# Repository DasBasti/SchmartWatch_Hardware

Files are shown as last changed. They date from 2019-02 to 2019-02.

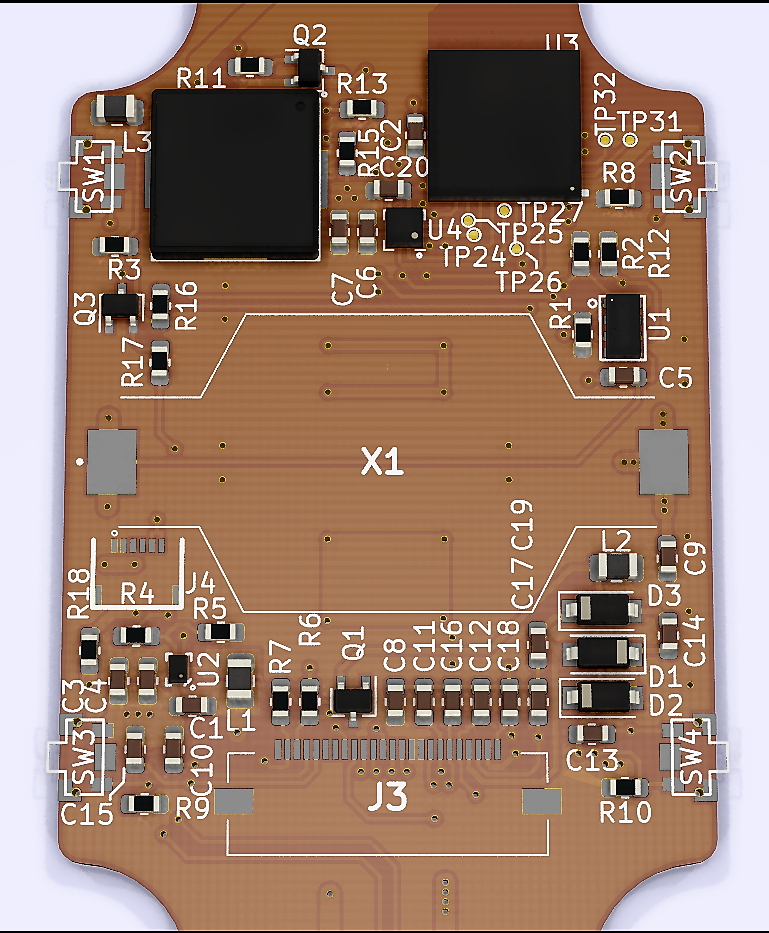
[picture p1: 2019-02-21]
render.png

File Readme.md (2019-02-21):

# Schmart Watch Hardware
Image of PCB rendering
## Table of Contents

- [Introduction](#introduction)
- [Terms of Use](#terms-of-use)
- [Problems?](#problems)
- [Changelog](#changelog)

## Introduction

This application is the hardware for the DIY Smartwatch project [Schmart Watch](http://www.kurzschluss-blog.de/2018/07/schmartwatch-01-smartwatch-selbst-gebaut.html).

To open the project you need [KiCad Version 5.0.0-rc2](http://kicad-pcb.org/) or newer.

## Terms of Use

Refer to "License.txt" for terms of use.

## Problems?

If you have any problems or questions, please ensure you have read this readme
file. If you are still having trouble, you can
[get in contact](https://plus.google.com/+BastianNeumann_DasBasti).

## Changelog

1. 2019-02-20: Version 0.1
  - Initial release of hardware version E3 for review

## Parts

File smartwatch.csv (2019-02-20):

Source: | C:\Users\Bastian\Documents\SmartWatch\Hardware\E3\smartwatch\smartwatch.sch
Date: | 24/09/2018 22:39:27
Tool: | Eeschema (5.0.0-rc2-109-g0e3be5776)
Generator: | C:\Program Files\KiCad\bin\scripting\plugins/bom_csv_grouped_by_value.py
Component Count: | 61
Individual Components:
Item | Qty | Reference(s) | Value | LibPart | Footprint | Datasheet | MPN1 | MPN2 | Package | Price | Status | Supplyer and ref
 |  | C1 | 10u/4V | Device:C | Capacitor_SMD:C_0603_1608Metric | https://www.mouser.de/datasheet/2/212/KEM_C1006_X5R_SMD-1103249.pdf | CL10A106MQ8NNNC | GRM188R60J106ME84D | 603 | 0,02363
 |  | C2 | 100n/6.3V | Device:C | Capacitor_SMD:C_0603_1608Metric | https://www.mouser.de/datasheet/2/281/murata_03052018_GRM_Series_1-1310166.pdf | GCM188R71C104KA37D | 0603YC104MAT2A | 603 | 0,01188
 |  | C3 | 10u/4V | Device:C | Capacitor_SMD:C_0603_1608Metric | https://www.mouser.de/datasheet/2/212/KEM_C1006_X5R_SMD-1103249.pdf | CL10A106MQ8NNNC | GRM188R60J106ME84D | 603 | 0,02363
 |  | C4 | 10u/4V | Device:C | Capacitor_SMD:C_0603_1608Metric | https://www.mouser.de/datasheet/2/212/KEM_C1006_X5R_SMD-1103249.pdf | CL10A106MQ8NNNC | GRM188R60J106ME84D | 603 | 0,02363
 |  | C5 | 100n/6.3V | Device:C | Capacitor_SMD:C_0603_1608Metric | https://www.mouser.de/datasheet/2/281/murata_03052018_GRM_Series_1-1310166.pdf | GCM188R71C104KA37D | 0603YC104MAT2A | 603 | 0,01188
 |  | C6 | 10u/4V | Device:C | Capacitor_SMD:C_0603_1608Metric | https://www.mouser.de/datasheet/2/212/KEM_C1006_X5R_SMD-1103249.pdf | CL10A106MQ8NNNC | GRM188R60J106ME84D | 603 | 0,02363
 |  | C7 | 10u/4V | Device:C | Capacitor_SMD:C_0603_1608Metric | https://www.mouser.de/datasheet/2/212/KEM_C1006_X5R_SMD-1103249.pdf | CL10A106MQ8NNNC | GRM188R60J106ME84D | 603 | 0,02363
 |  | C8 | 100n/6.3V | Device:C | Capacitor_SMD:C_0603_1608Metric | https://www.mouser.de/datasheet/2/281/murata_03052018_GRM_Series_1-1310166.pdf | GCM188R71C104KA37D | 0603YC104MAT2A | 603 | 0,01188
 |  | C9 | 4.7u/6.3V | Device:C | Capacitor_SMD:C_0603_1608Metric | https://www.mouser.de/datasheet/2/281/murata_03052018_GRM_Series_1-1310166.pdf | GRT188C80J475ME01D | CGA3E1X5R0J475K080AC | 603 | 0,04916
 |  | C10 | 1u/35V | Device:C | Capacitor_SMD:C_0603_1608Metric | https://www.mouser.de/datasheet/2/400/lcc_commercial_general_en-837201.pdf | C1608X7R1V105K080AC |  | 603 | 0,1043 | NRND
 |  | C11 | 1u/35V | Device:C | Capacitor_SMD:C_0603_1608Metric | https://www.mouser.de/datasheet/2/400/lcc_commercial_general_en-837201.pdf | C1608X7R1V105K080AC |  | 603 | 0,1043 | NRND
 |  | C12 | 1u/35V | Device:C | Capacitor_SMD:C_0603_1608Metric | https://www.mouser.de/datasheet/2/400/lcc_commercial_general_en-837201.pdf | C1608X7R1V105K080AC |  | 603 | 0,1043 | NRND
 |  | C13 | 1u/50V | Device:C | Capacitor_SMD:C_0603_1608Metric | https://www.mouser.de/datasheet/2/400/lcc_automotive_general_en-843974.pdf | GRT188R61H105KE13D | GRT188R61H105ME13D | 603 | 0,04035
 |  | C14 | 4.7u/6.3V | Device:C | Capacitor_SMD:C_0603_1608Metric | https://www.mouser.de/datasheet/2/281/murata_03052018_GRM_Series_1-1310166.pdf | GRT188C80J475ME01D | CGA3E1X5R0J475K080AC | 603 | 0,04916
 |  | C15 | 1u/35V | Device:C | Capacitor_SMD:C_0603_1608Metric | https://www.mouser.de/datasheet/2/400/lcc_commercial_general_en-837201.pdf | C1608X7R1V105K080AC |  | 603 | 0,1043 | NRND
 |  | C16 | 1u/35V | Device:C | Capacitor_SMD:C_0603_1608Metric | https://www.mouser.de/datasheet/2/400/lcc_commercial_general_en-837201.pdf | C1608X7R1V105K080AC |  | 603 | 0,1043 | NRND
 |  | C17 | 1u/35V | Device:C | Capacitor_SMD:C_0603_1608Metric | https://www.mouser.de/datasheet/2/400/lcc_commercial_general_en-837201.pdf | C1608X7R1V105K080AC |  | 603 | 0,1043 | NRND
 |  | C18 | 1u/35V | Device:C | Capacitor_SMD:C_0603_1608Metric | https://www.mouser.de/datasheet/2/400/lcc_commercial_general_en-837201.pdf | C1608X7R1V105K080AC |  | 603 | 0,1043 | NRND
 |  | C19 | 1u/50V | Device:C | Capacitor_SMD:C_0603_1608Metric | https://www.mouser.de/datasheet/2/400/lcc_automotive_general_en-843974.pdf | GRT188R61H105KE13D | GRT188R61H105ME13D | 603 | 0,04035
 |  | C20 | 22n/6.3V | Device:C | Capacitor_SMD:C_0603_1608Metric | https://www.mouser.de/datasheet/2/396/mlcc02_e-1307760.pdf | GRM188R71H223KA01D | C1608X8R1H223K080AA | 603 | 0,01472
 |  | D1 | MBR0530 | Diode:MBR0530 | Diode_SMD:D_SOD-123 | https://www.fairchildsemi.com/datasheets/MB/MBR0530.pdf | MBR0530 | MBR0530L-TP | SOD-123 | 0,33
 |  | D2 | MBR0530 | Diode:MBR0530 | Diode_SMD:D_SOD-123 | https://www.fairchildsemi.com/datasheets/MB/MBR0530.pdf | MBR0530 | MBR0530L-TP | SOD-123 | 0,33 |  | ff
 |  | D3 | MBR0530 | Diode:MBR0530 | Diode_SMD:D_SOD-123 | https://www.fairchildsemi.com/datasheets/MB/MBR0530.pdf | MBR0530 | MBR0530L-TP | SOD-123 | 0,33
 |  | J1 | 505148-0408 | Connector_Generic:Conn_01x04 | ProjectSpecific:505148-0408 | https://www.mouser.de/datasheet/2/276/5051480408_ACCESSORIES-844014.pdf | 505148-0408 |  |  | 0,3216
 |  | J2 | 505147-0490 | Connector_Generic:Conn_01x04 | ProjectSpecific:505147-0490_NO_SOLDER | https://www.mouser.de/datasheet/2/276/5051470290_FFC_FPC_CONNECTORS-843962.pdf | 505147-0490 |  |  | 0,73
 |  | J3 | 505110-2491 | Connector_Generic:Conn_01x24 | ProjectSpecific:MOLEX_FPC_24_P0.5mm_505110-2491 | https://www.mouser.de/datasheet/2/276/5051102491_FFC_FPC_CONNECTORS-705759.pdf | 505110-2491 |  |  | 0,87
 |  | J4 | Conn_01x06 | Connector_Generic:Conn_01x06 | ProjectSpecific:503480-0600 | ~ | 503480-0600 |  |  | 0,69
 |  | L1 | 2u2/650mA | Device:L | Inductor_SMD:L_0805_2012Metric | https://www.mouser.de/datasheet/2/396/CKP1608D2R2M-T_SS-1291418.pdf | MBKK2012T2R2M | GLF2012T2R2M | 805 | 0,2
 |  | L2 | 10u/520mA | Device:L | Inductor_SMD:L_0805_2012Metric | https://www.mouser.de/datasheet/2/212/F3115-1140376.pdf | CB2012T100KR | CB2012T100MR | 805 | 0,2
 |  | L3 | 2u2/650mA | Device:L | Inductor_SMD:L_0805_2012Metric | https://www.mouser.de/datasheet/2/396/CKP1608D2R2M-T_SS-1291418.pdf | MBKK2012T2R2M | GLF2012T2R2M | 805 | 0,2
 |  | NOBOM1 | GDEW0154Z17 | ProjectSpecific:GDEW0154Z17 |  | http://www.good-display.com/downloadsfront.do?id=95e3da56-1b2c-49e7-993f-ae6909170253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 | GDEW0154Z17 |  |  | 4,4 | NOBOM
 |  | Q1 | Si1308EDL | Transistor_FET:BSP129 | Package_TO_SOT_SMD:SOT-323_SC-70 | https://www.mouser.de/datasheet/2/427/si1308edl-256534.pdf | SI1308EDL-T1-GE3 |  | SOT-323 | 0,5
 |  | Q2 | Si1308EDL | Transistor_FET:BSP129 | Package_TO_SOT_SMD:SOT-323_SC-70 | https://www.mouser.de/datasheet/2/427/si1308edl-256534.pdf | SI1308EDL-T1-GE3 |  | SOT-323 | 0,5
 |  | Q3 | Si1308EDL | Transistor_FET:BSP129 | Package_TO_SOT_SMD:SOT-323_SC-70 | https://www.mouser.de/datasheet/2/427/si1308edl-256534.pdf | SI1308EDL-T1-GE3 |  | SOT-323 | 0,5
 |  | R1 | 10k | Device:R | Resistor_SMD:R_0603_1608Metric | https://www.mouser.de/datasheet/2/427/crcwce3-1223726.pdf | RMCF0603JG10K0 | CR0603-JW-103ELF | 603 | 0,09
 |  | R2 | 10k | Device:R | Resistor_SMD:R_0603_1608Metric | https://www.mouser.de/datasheet/2/427/crcwce3-1223726.pdf | RMCF0603JG10K0 | CR0603-JW-103ELF | 603 | 0,09
 |  | R3 | 10k | Device:R | Resistor_SMD:R_0603_1608Metric | https://www.mouser.de/datasheet/2/427/crcwce3-1223726.pdf | RMCF0603JG10K0 | CR0603-JW-103ELF | 603 | 0,09
 |  | R4 | 3R | Device:R | Resistor_SMD:R_0603_1608Metric | https://www.mouser.de/datasheet/2/447/PYu-AC_51_RoHS_L_6-1152827.pdf | RMCF0603JT3R00 | CR0603-J/-3R0ELF | 603 | 0,09
 |  | R5 | R | Device:R | Resistor_SMD:R_0603_1608Metric | ~ |  |  | 603 |  | DNP
 |  | R6 | 3R | Device:R | Resistor_SMD:R_0603_1608Metric | https://www.mouser.de/datasheet/2/447/PYu-AC_51_RoHS_L_6-1152827.pdf | RMCF0603JT3R00 | CR0603-J/-3R0ELF | 603 | 0,09
 |  | R7 | 10k | Device:R | Resistor_SMD:R_0603_1608Metric | https://www.mouser.de/datasheet/2/427/crcwce3-1223726.pdf | RMCF0603JG10K0 | CR0603-JW-103ELF | 603 | 0,09
 |  | R8 | 10k | Device:R | Resistor_SMD:R_0603_1608Metric | https://www.mouser.de/datasheet/2/427/crcwce3-1223726.pdf | RMCF0603JG10K0 | CR0603-JW-103ELF | 603 | 0,09
 |  | R9 | 10k | Device:R | Resistor_SMD:R_0603_1608Metric | https://www.mouser.de/datasheet/2/427/crcwce3-1223726.pdf | RMCF0603JG10K0 | CR0603-JW-103ELF | 603 | 0,09
 |  | R10 | 10k | Device:R | Resistor_SMD:R_0603_1608Metric | https://www.mouser.de/datasheet/2/427/crcwce3-1223726.pdf | RMCF0603JG10K0 | CR0603-JW-103ELF | 603 | 0,09
 |  | R11 | 10k | Device:R | Resistor_SMD:R_0603_1608Metric | https://www.mouser.de/datasheet/2/427/crcwce3-1223726.pdf | RMCF0603JG10K0 | CR0603-JW-103ELF | 603 | 0,09
 |  | R12 | 10k | Device:R | Resistor_SMD:R_0603_1608Metric | https://www.mouser.de/datasheet/2/427/crcwce3-1223726.pdf | RMCF0603JG10K0 | CR0603-JW-103ELF | 603 | 0,09
 |  | R13 | 100k | Device:R | Resistor_SMD:R_0603_1608Metric | https://www.mouser.de/datasheet/2/427/crcwce3-1223726.pdf | RMCF0603JG100K | CR0603-JW-104ELF | 603 | 0,09
 |  | R14 | R | Device:R | Resistor_SMD:R_0805_2012Metric | ~ |  |  | 805
 |  | R15 | 100k | Device:R | Resistor_SMD:R_0603_1608Metric | https://www.mouser.de/datasheet/2/427/crcwce3-1223726.pdf | RMCF0603JG100K | CR0603-JW-104ELF | 603 | 0,09
 |  | R16 | 10k | Device:R | Resistor_SMD:R_0603_1608Metric | https://www.mouser.de/datasheet/2/447/PYu-AC_51_RoHS_L_6-1152827.pdf | RMCF0603JG10K0 | CR0603-JW-103ELF | 603 | 0,09
 |  | R17 | 3R | Device:R | Resistor_SMD:R_0603_1608Metric | https://www.mouser.de/datasheet/2/447/PYu-AC_51_RoHS_L_6-1152827.pdf | RMCF0603JT3R00 | CR0603-J/-3R0ELF | 603 | 0,09
 |  | SW1 | SKTDLDE010 | ProjectSpecific:SKTGLBE010 | ProjectSpecific:SKTDLDE010 | https://www.mouser.de/datasheet/2/15/SKTD-1370729.pdf | SKTDLDE010 |  |  | 0,475
 |  | SW2 | SKTDLDE010 | ProjectSpecific:SKTGLBE010 | ProjectSpecific:SKTDLDE010 | https://www.mouser.de/datasheet/2/15/SKTD-1370729.pdf | SKTDLDE010 |  |  | 0,475
 |  | SW3 | SKTDLDE010 | ProjectSpecific:SKTGLBE010 | ProjectSpecific:SKTDLDE010 | https://www.mouser.de/datasheet/2/15/SKTD-1370729.pdf | SKTDLDE010 |  |  | 0,475
 |  | SW4 | SKTDLDE010 | ProjectSpecific:SKTGLBE010 | ProjectSpecific:SKTDLDE010 | https://www.mouser.de/datasheet/2/15/SKTD-1370729.pdf | SKTDLDE010 |  |  | 0,475
 |  | U1 | M41T62LC6F | ProjectSpecific:M41T62LC6F | ProjectSpecific:LCC-8_1.5x3.2mm_P0.9mm | https://www.mouser.de/datasheet/2/389/m41t62-955028.pdf | M41T62LC6F |  | LCC | 3,33
 |  | U2 | TPS610994 | ProjectSpecific:TPS61099x | ProjectSpecific:BGA-6_2x3_1.0x1.35mm | http://www.ti.com/lit/gpn/tps61099 | TPS610994 |  | BGA | 1,32
 |  | U3 | ISP1507-AX | ProjectSpecific:ISP1507-AX | ProjectSpecific:ISP1507-AX | https://www.mouser.de/datasheet/2/889/isp_ble_DS1507-1221980.pdf | ISP1507-AX |  | LGA | 10,73
 |  | U4 | LSM303AGR | ProjectSpecific:LSM303AGR | Package_LGA:LGA-12_2x2mm_P0.5mm | https://www.mouser.de/datasheet/2/389/lsm303agr-954987.pdf | LSM303AGR |  | LGA | 2,33
 |  | X1 | SMTU2032-LF | ProjectSpecific:SMTU2032-LF | ProjectSpecific:SMTU2032-LF-6066 | https://www.mouser.de/datasheet/2/346/SMTU2032-LF-6066.pdf | SMTU2032-LF |  |  | 0,886
 |  | X2 | SMT-0940-T-3V-R | ProjectSpecific:SMT-0940-T-3V-R | ProjectSpecific:SMT-0940-T_3V-R |  | SMT-0940-T-3V-R |  |  | 3,55
Collated Components:
Item | Qty | Reference(s) | Value | LibPart | Footprint | Datasheet | MPN1 | MPN2 | Package | Price | Status | Supplyer and ref
1 | 5 | C1, C3, C4, C6, C7 | 10u/4V | Device:C | Capacitor_SMD:C_0603_1608Metric | https://www.mouser.de/datasheet/2/212/KEM_C1006_X5R_SMD-1103249.pdf | CL10A106MQ8NNNC | GRM188R60J106ME84D | 603 | 0,02363
2 | 3 | C2, C5, C8 | 100n/6.3V | Device:C | Capacitor_SMD:C_0603_1608Metric | https://www.mouser.de/datasheet/2/281/murata_03052018_GRM_Series_1-1310166.pdf | GCM188R71C104KA37D | 0603YC104MAT2A | 603 | 0,01188
3 | 2 | C9, C14 | 4.7u/6.3V | Device:C | Capacitor_SMD:C_0603_1608Metric | https://www.mouser.de/datasheet/2/281/murata_03052018_GRM_Series_1-1310166.pdf | GRT188C80J475ME01D | CGA3E1X5R0J475K080AC | 603 | 0,04916
4 | 7 | C10, C11, C12, C15, C16, C17, C18 | 1u/35V | Device:C | Capacitor_SMD:C_0603_1608Metric | https://www.mouser.de/datasheet/2/400/lcc_commercial_general_en-837201.pdf | C1608X7R1V105K080AC |  | 603 | 0,1043 | NRND
5 | 2 | C13, C19 | 1u/50V | Device:C | Capacitor_SMD:C_0603_1608Metric | https://www.mouser.de/datasheet/2/400/lcc_automotive_general_en-843974.pdf | GRT188R61H105KE13D | GRT188R61H105ME13D | 603 | 0,04035
6 | 1 | C20 | 22n/6.3V | Device:C | Capacitor_SMD:C_0603_1608Metric | https://www.mouser.de/datasheet/2/396/mlcc02_e-1307760.pdf | GRM188R71H223KA01D | C1608X8R1H223K080AA | 603 | 0,01472
7 | 3 | D1, D2, D3 | MBR0530 | Diode:MBR0530 | Diode_SMD:D_SOD-123 | https://www.fairchildsemi.com/datasheets/MB/MBR0530.pdf | MBR0530 | MBR0530L-TP | SOD-123 | 0,33 |  | ff
8 | 1 | J1 | 505148-0408 | Connector_Generic:Conn_01x04 | ProjectSpecific:505148-0408 | https://www.mouser.de/datasheet/2/276/5051480408_ACCESSORIES-844014.pdf | 505148-0408 |  |  | 0,3216
9 | 1 | J2 | 505147-0490 | Connector_Generic:Conn_01x04 | ProjectSpecific:505147-0490_NO_SOLDER | https://www.mouser.de/datasheet/2/276/5051470290_FFC_FPC_CONNECTORS-843962.pdf | 505147-0490 |  |  | 0,73
10 | 1 | J3 | 505110-2491 | Connector_Generic:Conn_01x24 | ProjectSpecific:MOLEX_FPC_24_P0.5mm_505110-2491 | https://www.mouser.de/datasheet/2/276/5051102491_FFC_FPC_CONNECTORS-705759.pdf | 505110-2491 |  |  | 0,87
11 | 1 | J4 | Conn_01x06 | Connector_Generic:Conn_01x06 | ProjectSpecific:503480-0600 | ~ | 503480-0600 |  |  | 0,69
12 | 2 | L1, L3 | 2u2/650mA | Device:L | Inductor_SMD:L_0805_2012Metric | https://www.mouser.de/datasheet/2/396/CKP1608D2R2M-T_SS-1291418.pdf | MBKK2012T2R2M | GLF2012T2R2M | 805 | 0,2
13 | 1 | L2 | 10u/520mA | Device:L | Inductor_SMD:L_0805_2012Metric | https://www.mouser.de/datasheet/2/212/F3115-1140376.pdf | CB2012T100KR | CB2012T100MR | 805 | 0,2
14 | 1 | NOBOM1 | GDEW0154Z17 | ProjectSpecific:GDEW0154Z17 |  | http://www.good-display.com/downloadsfront.do?id=95e3da56-1b2c-49e7-993f-ae6909170253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 | GDEW0154Z17 |  |  | 4,4 | NOBOM
15 | 3 | Q1, Q2, Q3 | Si1308EDL | Transistor_FET:BSP129 | Package_TO_SOT_SMD:SOT-323_SC-70 | https://www.mouser.de/datasheet/2/427/si1308edl-256534.pdf | SI1308EDL-T1-GE3 |  | SOT-323 | 0,5
16 | 10 | R1, R2, R3, R7, R8, R9, R10, R11, R12, R16 | 10k | Device:R | Resistor_SMD:R_0603_1608Metric | https://www.mouser.de/datasheet/2/427/crcwce3-1223726.pdf | RMCF0603JG10K0 | CR0603-JW-103ELF | 603 | 0,09
17 | 3 | R4, R6, R17 | 3R | Device:R | Resistor_SMD:R_0603_1608Metric | https://www.mouser.de/datasheet/2/447/PYu-AC_51_RoHS_L_6-1152827.pdf | RMCF0603JT3R00 | CR0603-J/-3R0ELF | 603 | 0,09
18 | 1 | R5 | R | Device:R | Resistor_SMD:R_0603_1608Metric | ~ |  |  | 603 |  | DNP
19 | 2 | R13, R15 | 100k | Device:R | Resistor_SMD:R_0603_1608Metric | https://www.mouser.de/datasheet/2/427/crcwce3-1223726.pdf | RMCF0603JG100K | CR0603-JW-104ELF | 603 | 0,09
20 | 1 | R14 | R | Device:R | Resistor_SMD:R_0805_2012Metric | ~ |  |  | 805
21 | 4 | SW1, SW2, SW3, SW4 | SKTDLDE010 | ProjectSpecific:SKTGLBE010 | ProjectSpecific:SKTDLDE010 | https://www.mouser.de/datasheet/2/15/SKTD-1370729.pdf | SKTDLDE010 |  |  | 0,475
22 | 1 | U1 | M41T62LC6F | ProjectSpecific:M41T62LC6F | ProjectSpecific:LCC-8_1.5x3.2mm_P0.9mm | https://www.mouser.de/datasheet/2/389/m41t62-955028.pdf | M41T62LC6F |  | LCC | 3,33
23 | 1 | U2 | TPS610994 | ProjectSpecific:TPS61099x | ProjectSpecific:BGA-6_2x3_1.0x1.35mm | http://www.ti.com/lit/gpn/tps61099 | TPS610994 |  | BGA | 1,32
24 | 1 | U3 | ISP1507-AX | ProjectSpecific:ISP1507-AX | ProjectSpecific:ISP1507-AX | https://www.mouser.de/datasheet/2/889/isp_ble_DS1507-1221980.pdf | ISP1507-AX |  | LGA | 10,73
25 | 1 | U4 | LSM303AGR | ProjectSpecific:LSM303AGR | Package_LGA:LGA-12_2x2mm_P0.5mm | https://www.mouser.de/datasheet/2/389/lsm303agr-954987.pdf | LSM303AGR |  | LGA | 2,33
26 | 1 | X1 | SMTU2032-LF | ProjectSpecific:SMTU2032-LF | ProjectSpecific:SMTU2032-LF-6066 | https://www.mouser.de/datasheet/2/346/SMTU2032-LF-6066.pdf | SMTU2032-LF |  |  | 0,886
27 | 1 | X2 | SMT-0940-T-3V-R | ProjectSpecific:SMT-0940-T-3V-R | ProjectSpecific:SMT-0940-T_3V-R |  | SMT-0940-T-3V-R |  |  | 3,55

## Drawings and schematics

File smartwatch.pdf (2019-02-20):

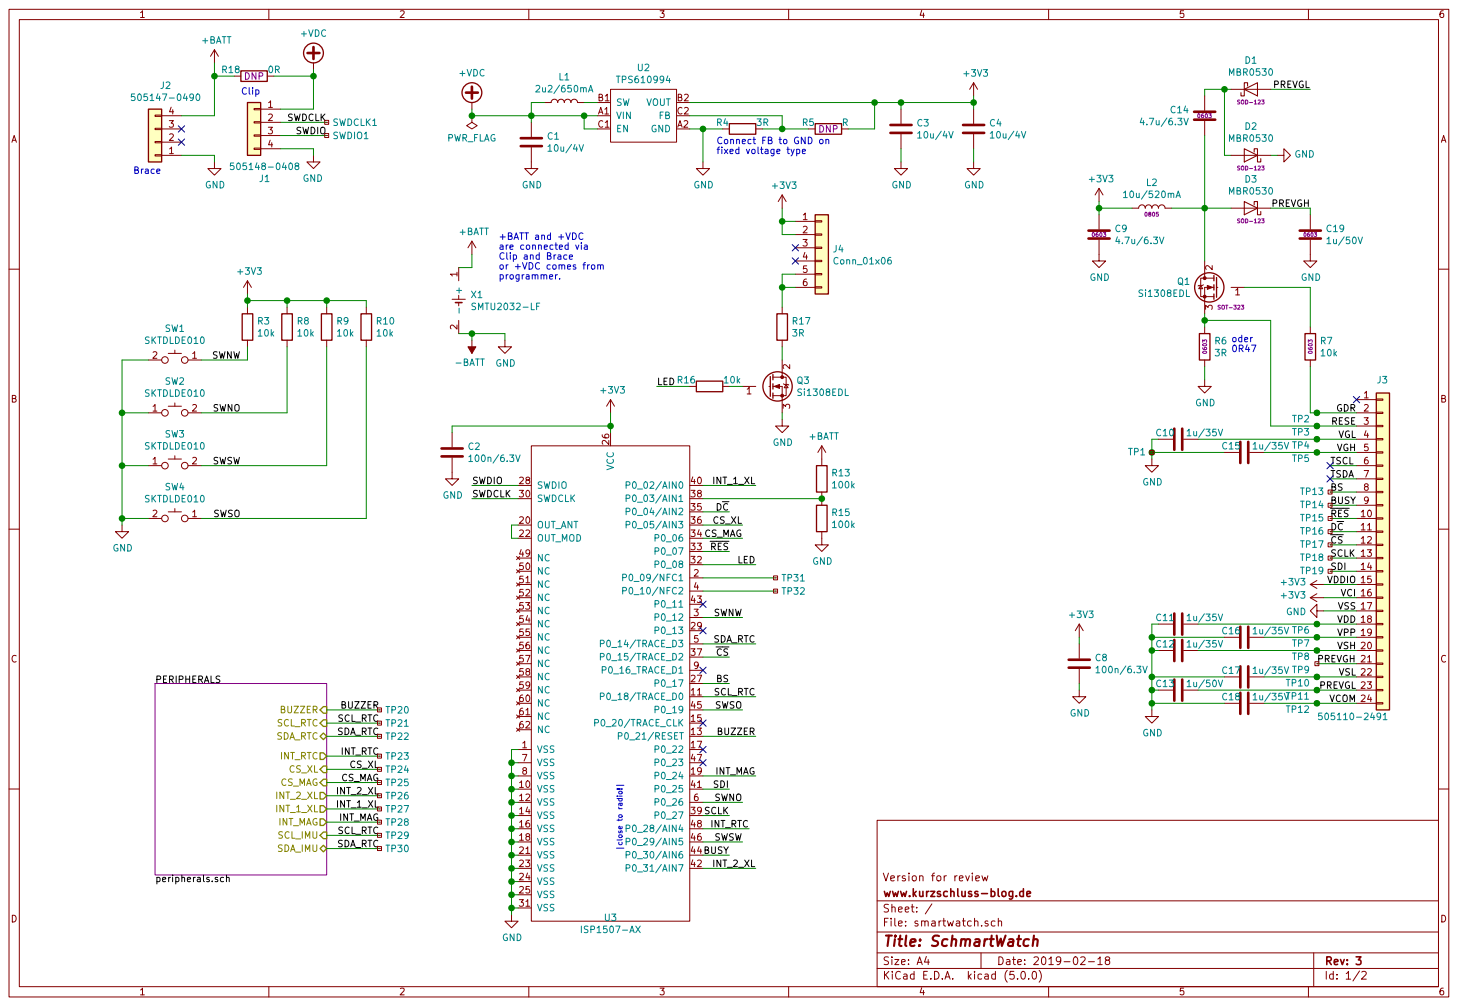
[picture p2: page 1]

fixed voltage type PERIPHERALS

+BATT and +VDC
are connected via Clip and Brace
or +VDC comes from

File: smartwatch.sch Sheet: / www.kurzschluss-blog.de Version for review

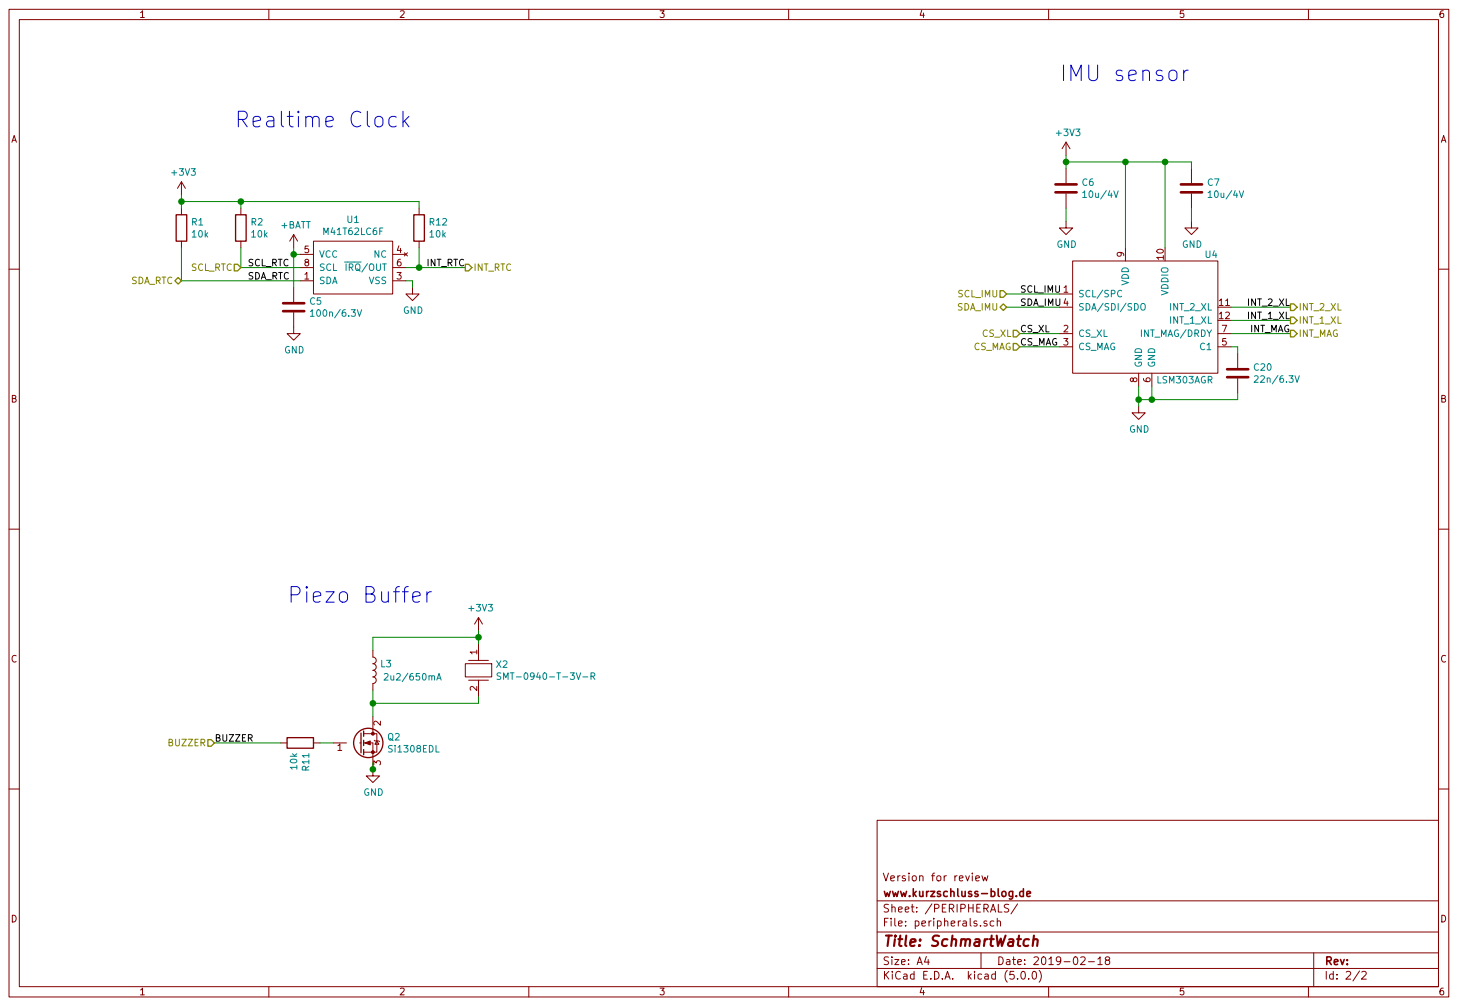
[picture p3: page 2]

File: peripherals.sch Sheet: /PERIPHERALS/ www.kurzschluss-blog.de Version for review

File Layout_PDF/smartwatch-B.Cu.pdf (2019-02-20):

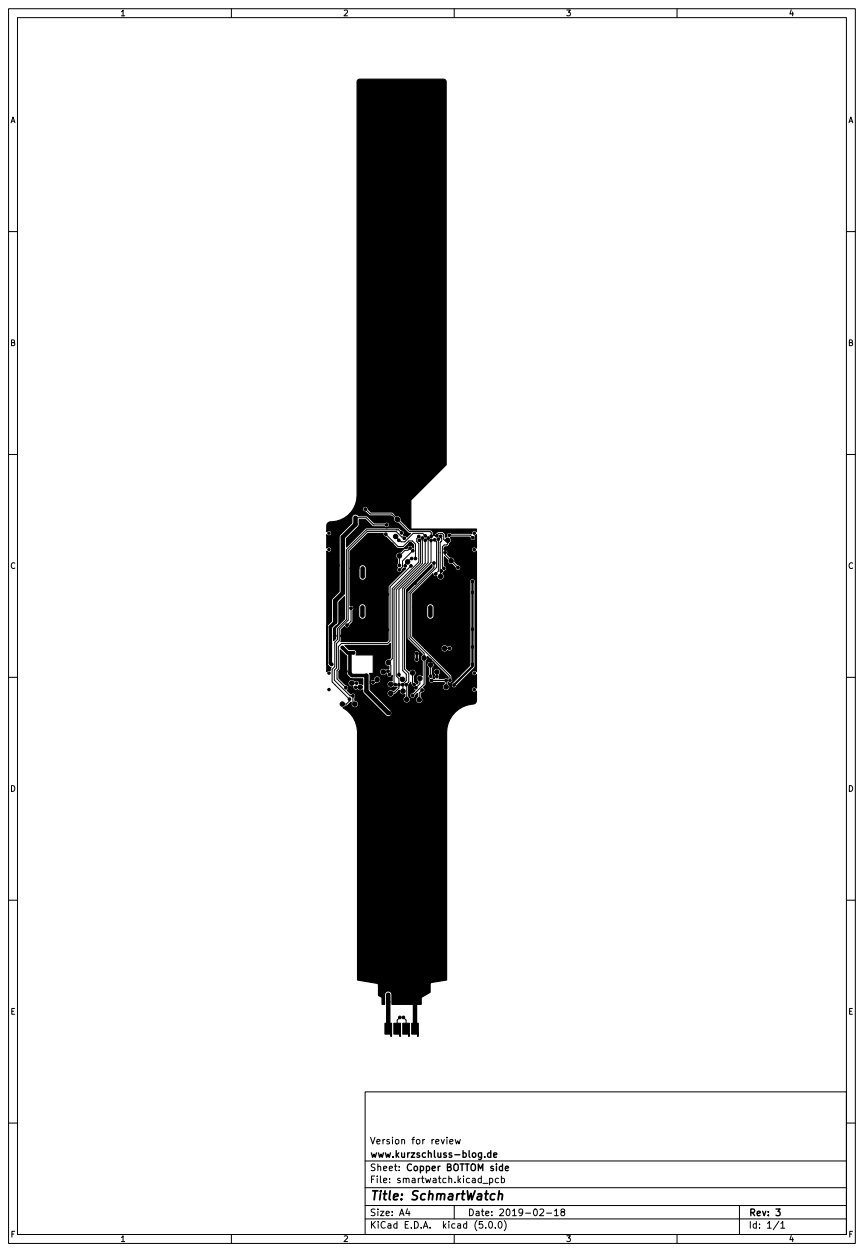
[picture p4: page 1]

File: smartwatch.kicad_pcb Sheet: www.kurzschluss-blog.de Version for review

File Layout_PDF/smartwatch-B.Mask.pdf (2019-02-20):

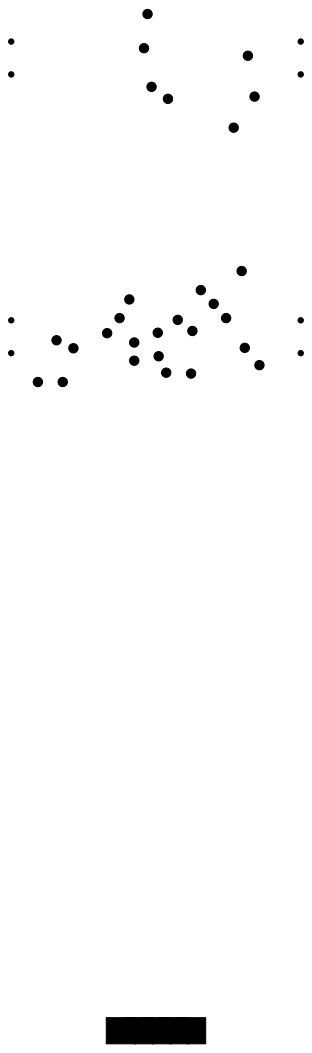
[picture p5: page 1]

File: smartwatch.kicad_pcb Sheet: www.kurzschluss-blog.de Version for review

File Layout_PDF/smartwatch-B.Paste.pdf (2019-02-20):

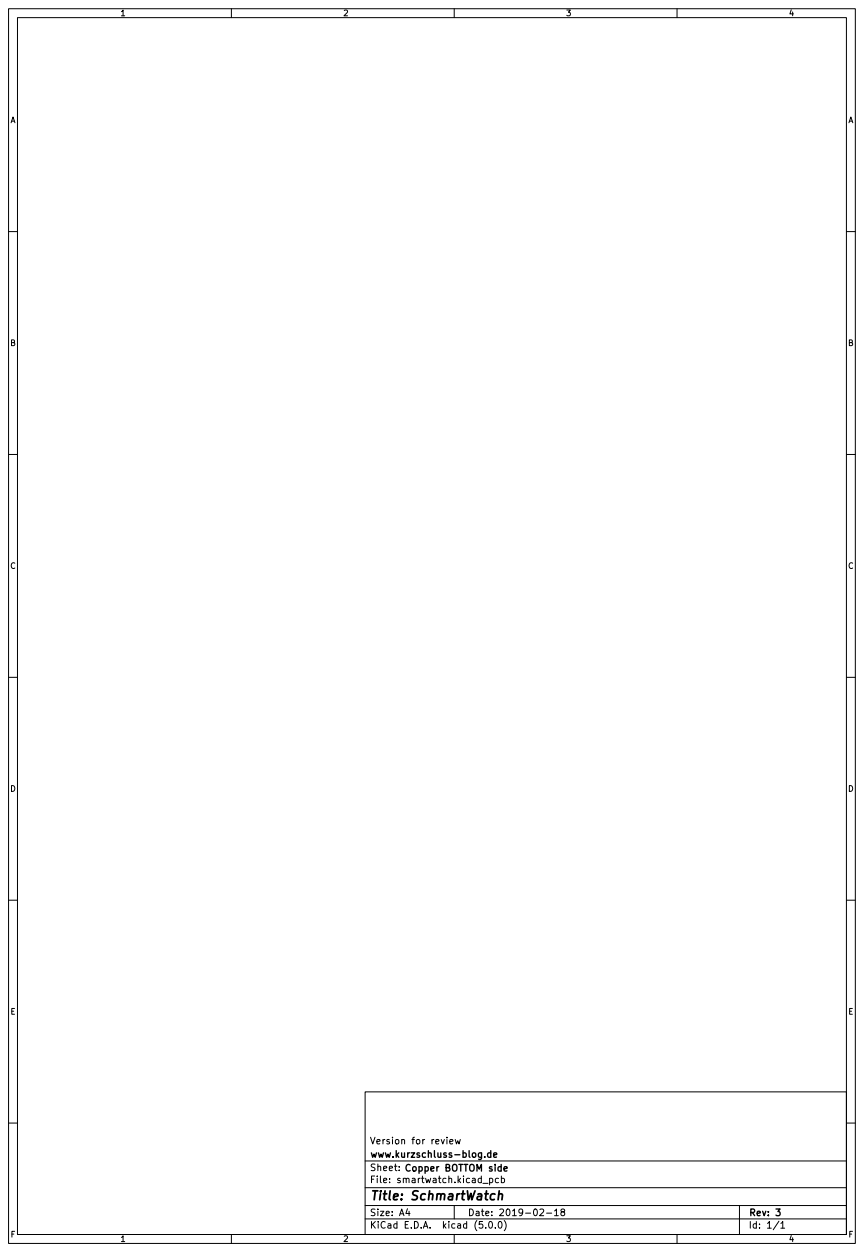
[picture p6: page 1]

File: smartwatch.kicad_pcb Sheet: www.kurzschluss-blog.de Version for review

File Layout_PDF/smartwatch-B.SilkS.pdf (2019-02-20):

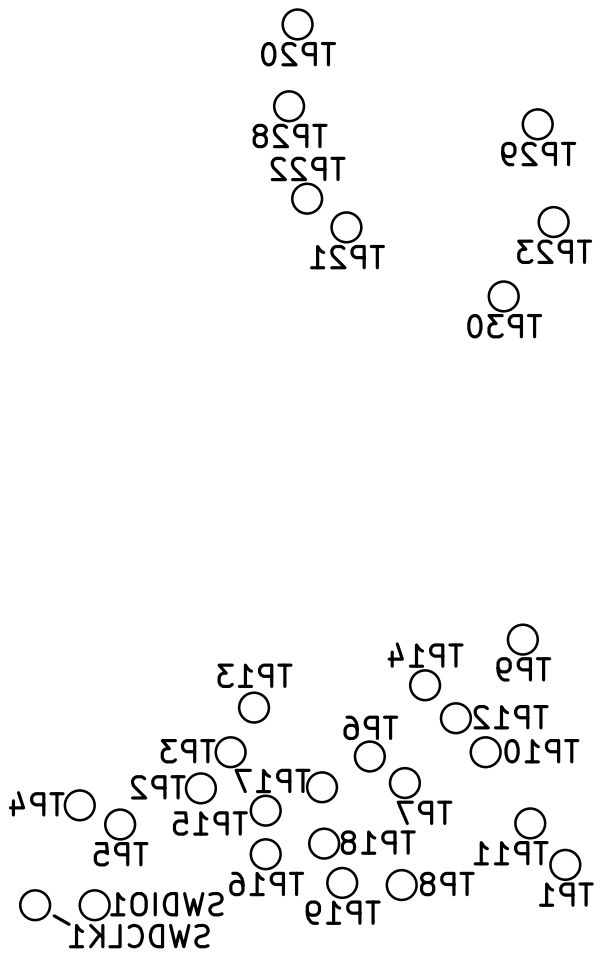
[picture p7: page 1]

File: smartwatch.kicad_pcb Sheet: www.kurzschluss-blog.de Version for review

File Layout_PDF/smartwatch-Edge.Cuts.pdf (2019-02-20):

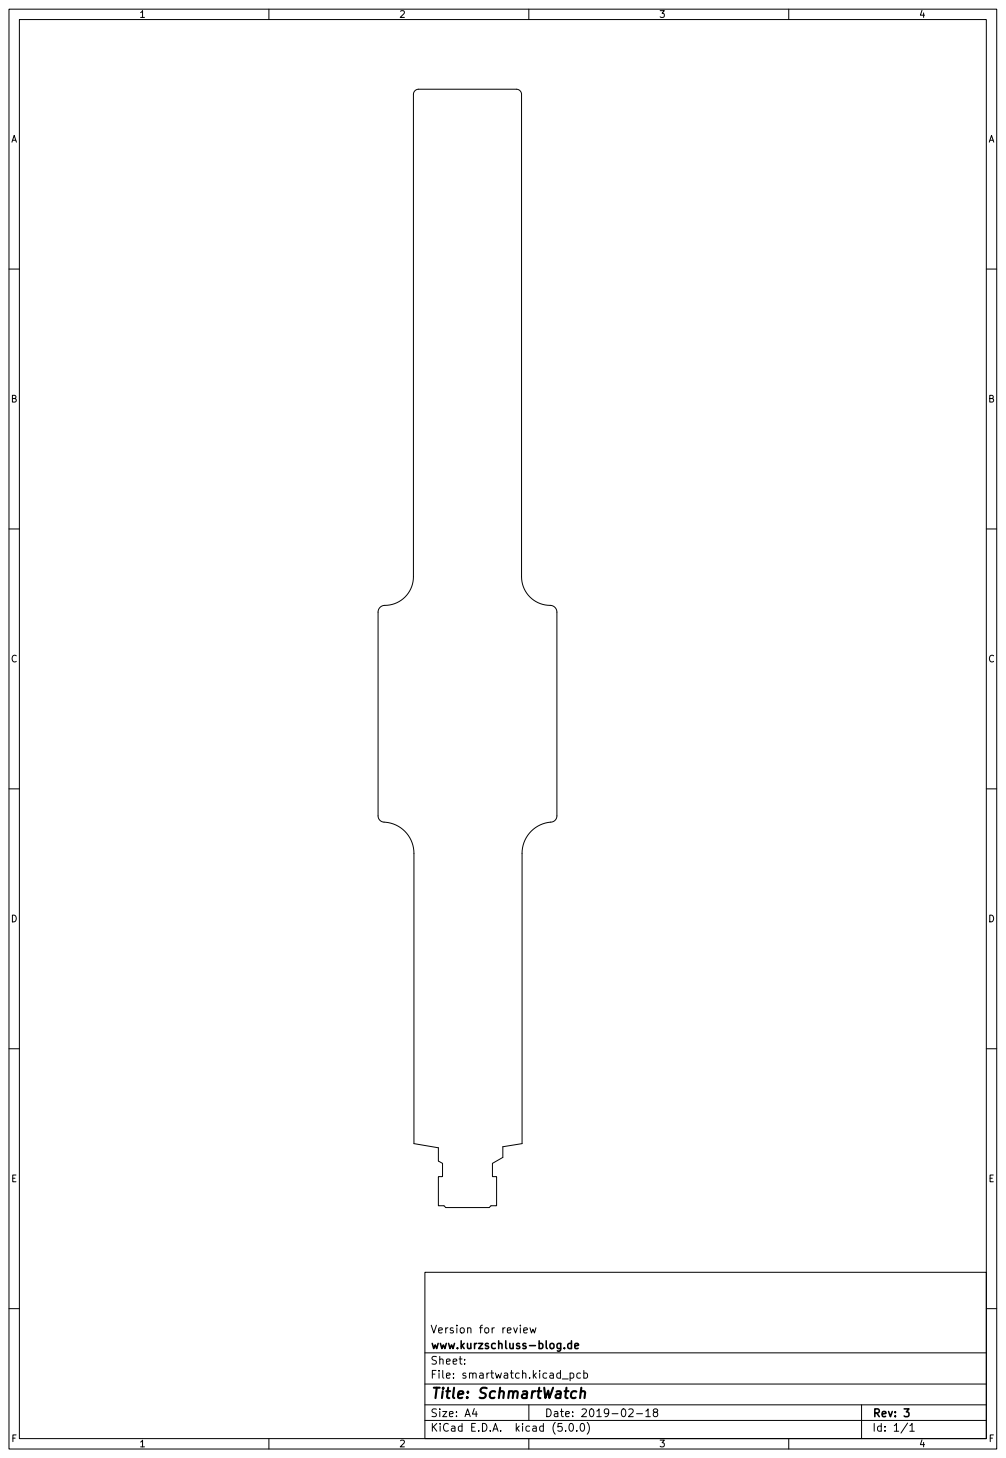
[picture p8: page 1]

File: smartwatch.kicad_pcb Sheet: www.kurzschluss-blog.de Version for review

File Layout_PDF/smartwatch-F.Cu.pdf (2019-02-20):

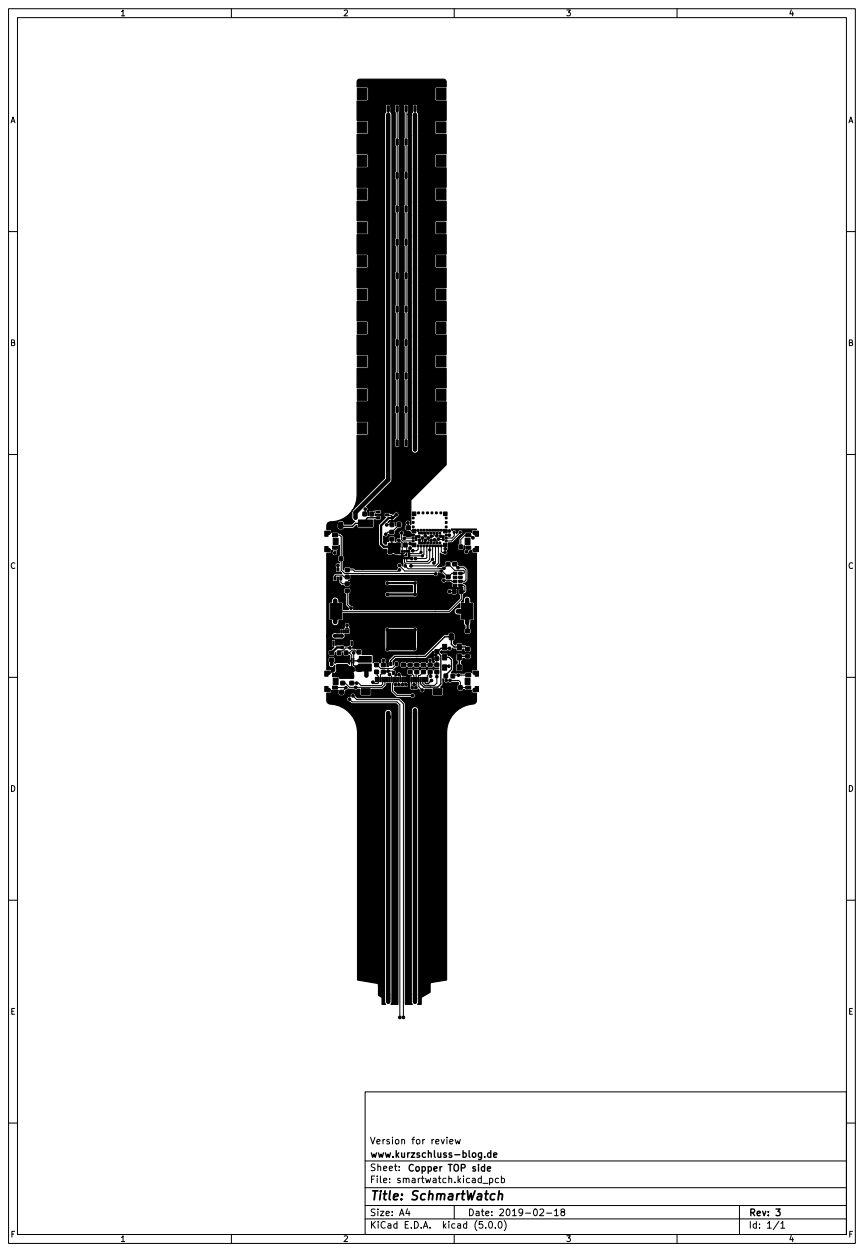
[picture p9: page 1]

File: smartwatch.kicad_pcb Sheet: www.kurzschluss-blog.de Version for review

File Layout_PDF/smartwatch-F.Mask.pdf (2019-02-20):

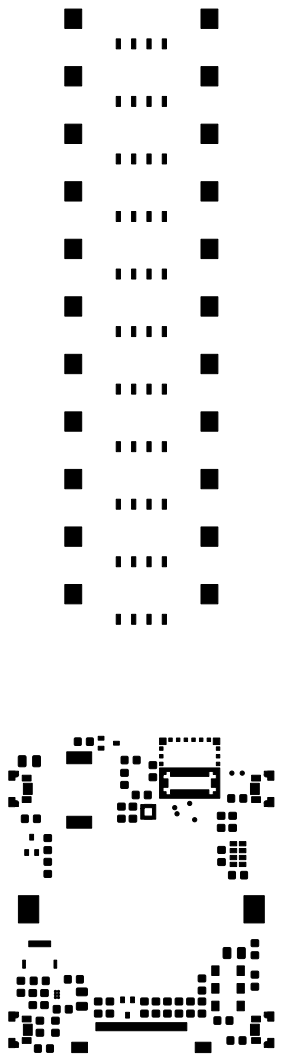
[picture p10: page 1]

File: smartwatch.kicad_pcb Sheet: www.kurzschluss-blog.de Version for review

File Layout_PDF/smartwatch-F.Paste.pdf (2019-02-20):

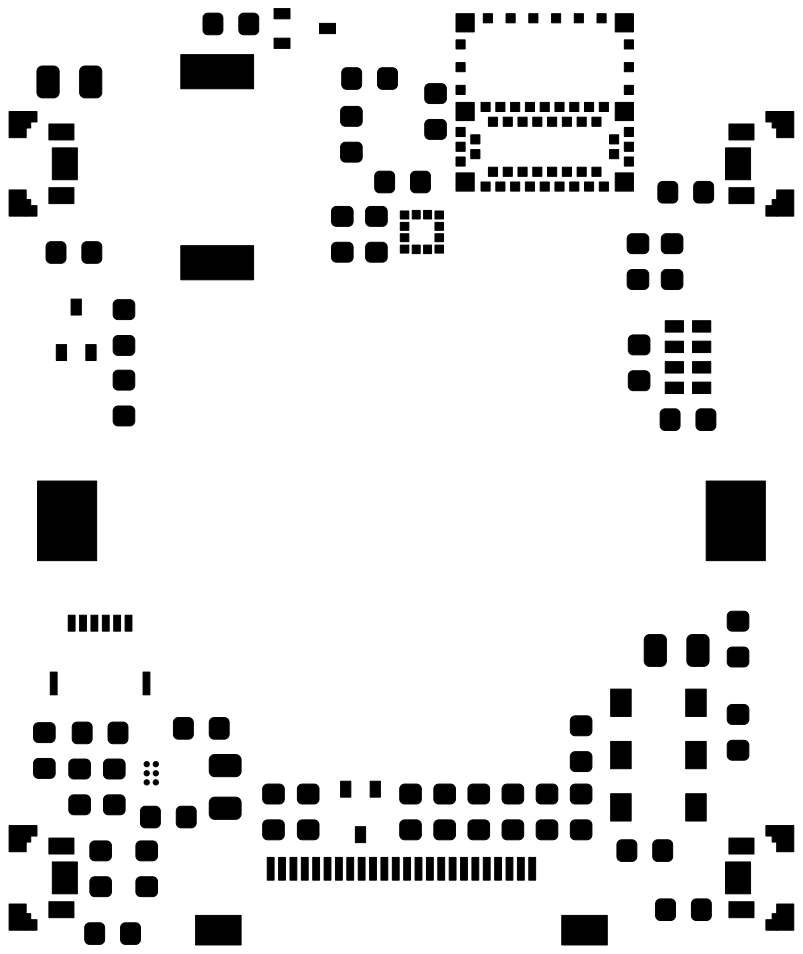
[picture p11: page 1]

File: smartwatch.kicad_pcb Sheet: www.kurzschluss-blog.de Version for review

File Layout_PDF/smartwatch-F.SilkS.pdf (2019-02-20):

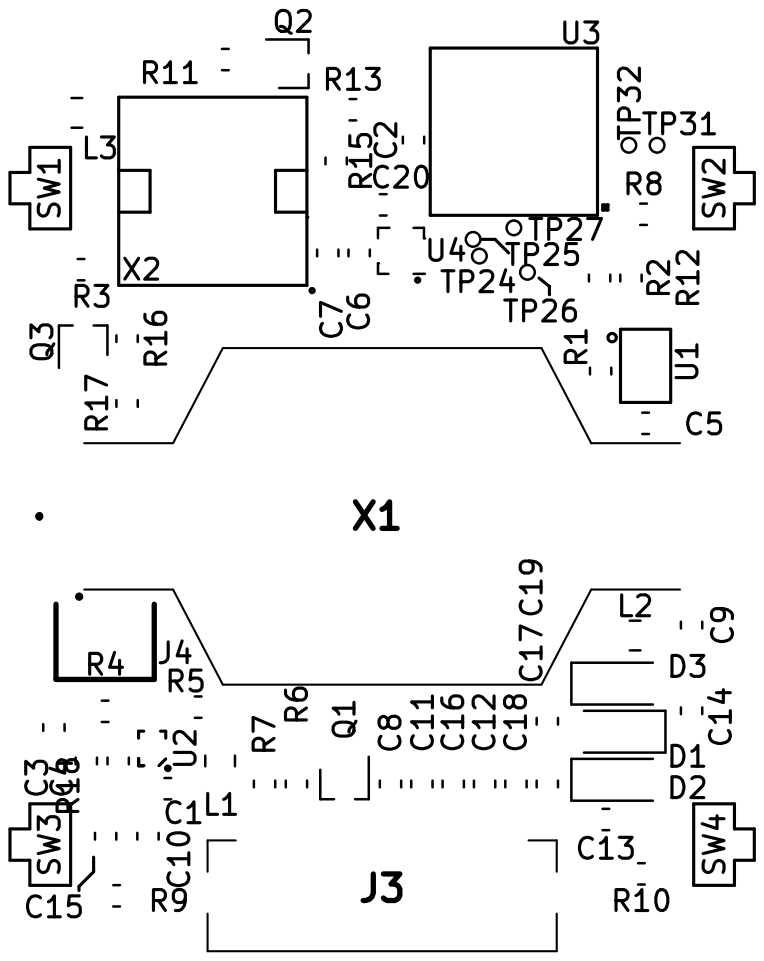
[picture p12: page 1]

File: smartwatch.kicad_pcb Sheet: www.kurzschluss-blog.de Version for review

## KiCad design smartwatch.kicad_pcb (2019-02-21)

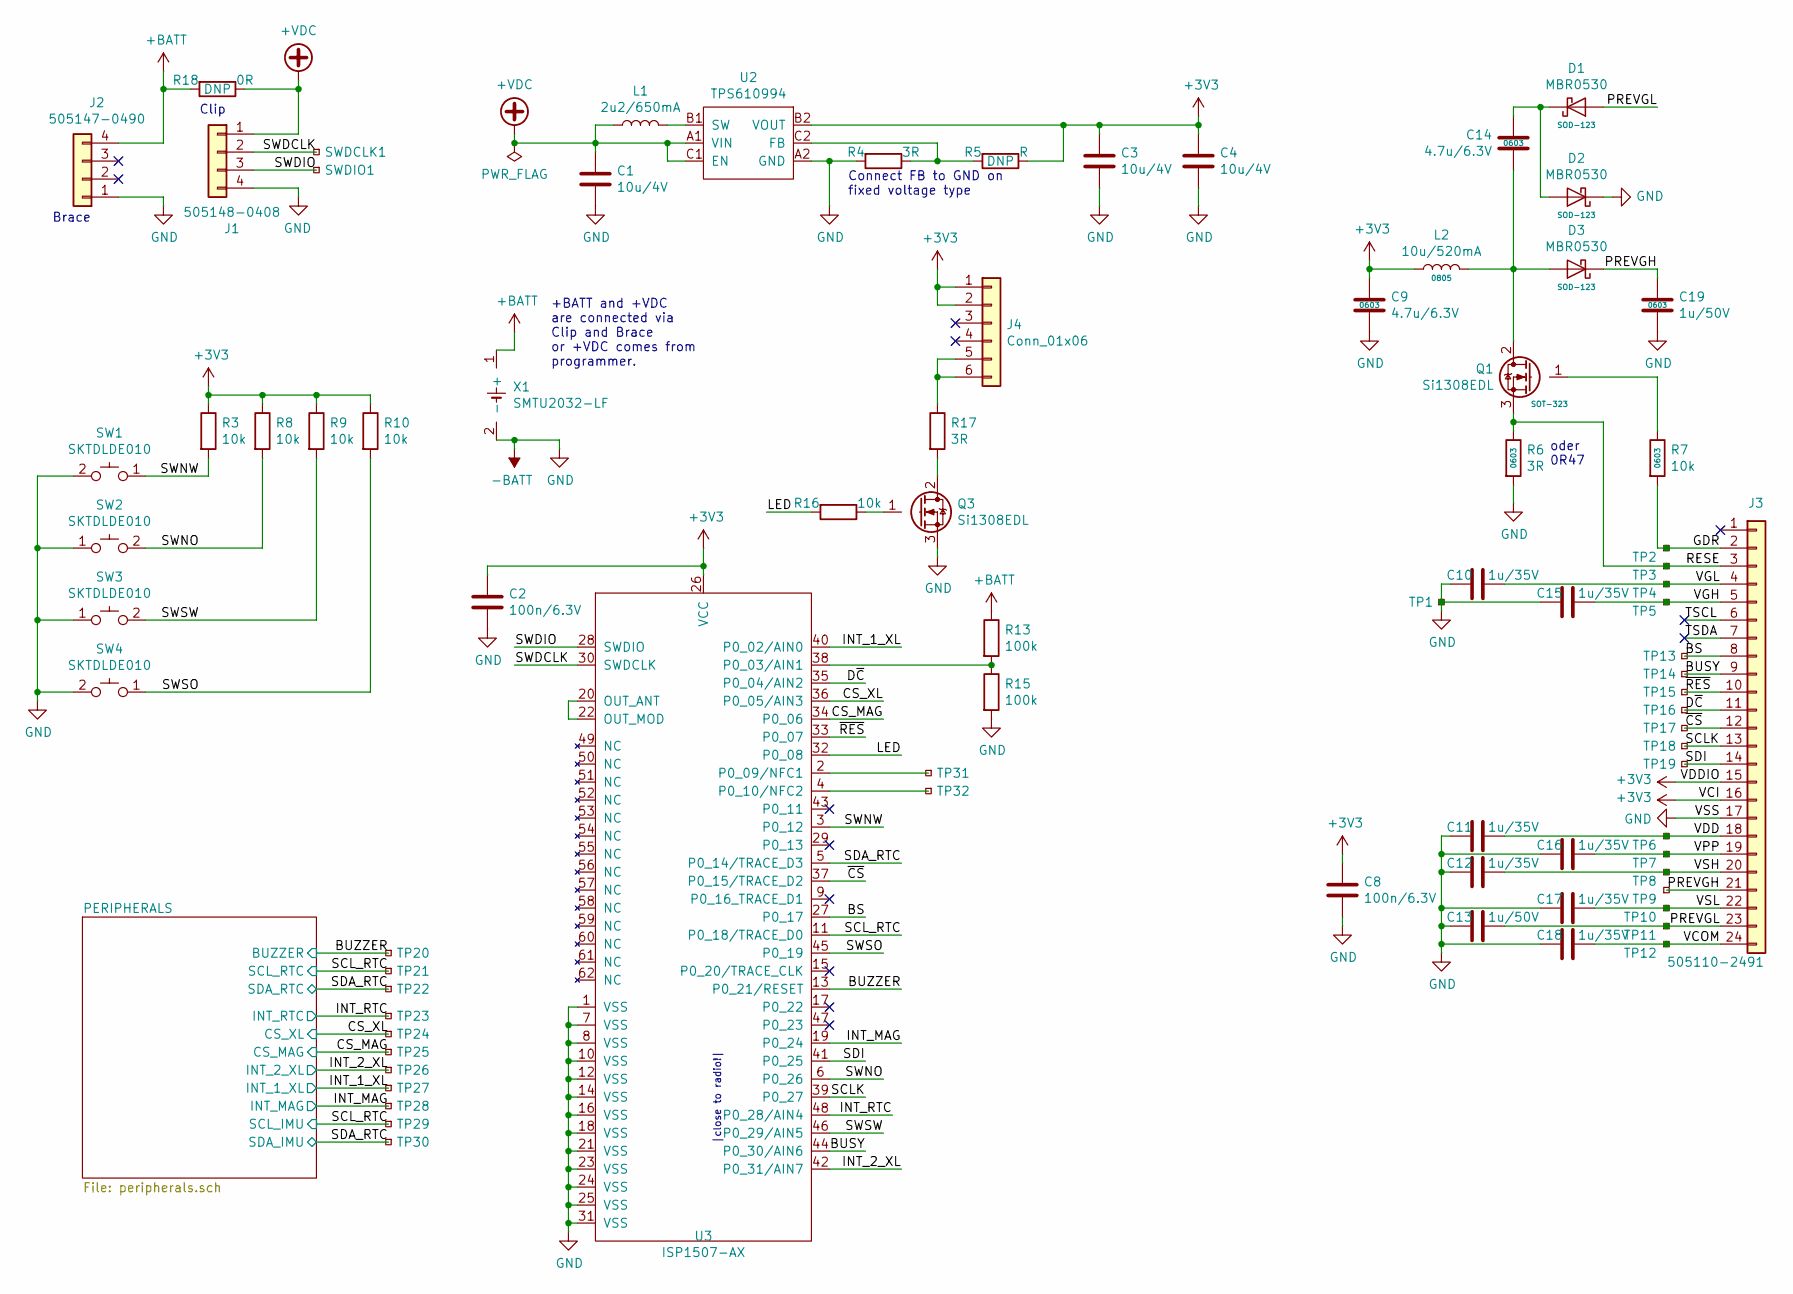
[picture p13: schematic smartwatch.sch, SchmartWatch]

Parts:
C1, C3, C4: 10u/4V; C_0603_1608Metric; MPN1 CL10A106MQ8NNNC
C2, C8: 100n/6.3V; C_0603_1608Metric; MPN1 GCM188R71C104KA37D
C9, C14: 4.7u/6.3V; C_0603_1608Metric; MPN1 GRT188C80J475ME01D
C10, C11, C12, C15, C16, C17, C18: 1u/35V; C_0603_1608Metric; MPN1 C1608X7R1V105K080AC
C13, C19: 1u/50V; C_0603_1608Metric; MPN1 GRT188R61H105KE13D
D1, D2, D3: MBR0530; D_SOD-123; MPN1 MBR0530
J1: 505148-0408; MPN1 505148-0408
J2: 505147-0490; 505147-0490_NO_SOLDER; MPN1 505147-0490
J3: 505110-2491; MOLEX_FPC_24_P0.5mm_505110-2491; MPN1 505110-2491
J4: Conn_01x06; 503480-0600; MPN1 503480-0600
L1: 2u2/650mA; L_0805_2012Metric; MPN1 MBKK2012T2R2M
L2: 10u/520mA; L_0805_2012Metric; MPN1 CB2012T100KR
Q1, Q3: Si1308EDL; SOT-323_SC-70; MPN1 SI1308EDL-T1-GE3
R3, R7, R8, R9, R10, R16: 10k; R_0603_1608Metric; MPN1 RMCF0603JG10K0
R4, R6, R17: 3R; R_0603_1608Metric; MPN1 RMCF0603JT3R00
R5: R; R_0603_1608Metric
R13, R15: 100k; R_0603_1608Metric; MPN1 RMCF0603JG100K
R18: 0R; R_0603_1608Metric
SW1, SW2, SW3, SW4: SKTDLDE010; MPN1 SKTDLDE010
SWDCLK1: TestPoint; TestPoint_Pad_D1.0mm
SWDIO1: TestPoint; TestPoint_Pad_D1.0mm
TP1, TP2, TP3, TP4, TP5, TP6, TP7, TP8, TP9, TP10, TP11, TP12, TP13, TP14, TP15, TP16, TP17, TP18, TP19, TP20, TP21, TP22, TP23, TP28, TP29, TP30: TestPoint; TestPoint_Pad_D1.0mm
TP24, TP25, TP26, TP27, TP31, TP32: TestPoint; TestPoint_Pad_D0.5mm
U2: TPS610994; BGA-6_2x3_1.0x1.35mm; MPN1 TPS610994
U3: ISP1507-AX; MPN1 ISP1507-AX
X1: SMTU2032-LF; SMTU2032-LF-6066; MPN1 SMTU2032-LF

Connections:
+3V3: C2.1, C3.1, C4.1, C8.1, C9.1, J2.~, J3.15, J3.16, J3.25, J3.26, J4.1, J4.2, J4.7, J4.8, L2.1, R3.1, R5.1, R8.1, R9.1, R10.1, U2.B2 (VOUT), U3.26 (VCC); also elsewhere on the board
+BATT: J2.4, R13.1, R18.2, X1.1 (+); also elsewhere on the board
+VDC: C1.1, J1.1, L1.1, R18.1, U2.A1 (VIN), U2.C1 (EN)
-BATT: C1.2, C2.2, C3.2, C4.2, C8.2, C9.2, C10.2, C11.2, C12.2, C13.2, C15.2, C16.2, C17.2, C18.2, C19.2, D2.1 (K), J1.4, J2.1, J3.17, Q3.3 (S), R4.2, R6.2, R15.2, SW1.2, SW2.1, SW3.1, SW4.2, TP1.1, U2.A2 (GND), U3.1 (VSS), U3.7 (VSS), U3.8 (VSS), U3.10 (VSS), U3.12 (VSS), U3.14 (VSS), U3.16 (VSS), U3.18 (VSS), U3.21 (VSS), U3.23 (VSS), U3.24 (VSS), U3.25 (VSS), U3.31 (VSS), X1.2 (-); also elsewhere on the board
/BS: J3.8, TP13.1, U3.27 (P0_17)
/BUSY: J3.9, TP14.1, U3.44 (P0_30/AIN6)
/BUZZER: TP20.1, U3.13 (P0_21/RESET); also elsewhere on the board
/CS_MAG: TP25.1, U3.34 (P0_06); also elsewhere on the board
/CS_XL: TP24.1, U3.36 (P0_05/AIN3); also elsewhere on the board
/D~C: J3.11, TP16.1, U3.35 (P0_04/AIN2)
/GDR: J3.2, R7.2, TP2.1
/INT_1_XL: TP27.1, U3.40 (P0_02/AIN0); also elsewhere on the board
/INT_2_XL: TP26.1, U3.42 (P0_31/AIN7); also elsewhere on the board
/INT_MAG: TP28.1, U3.19 (P0_24); also elsewhere on the board
/INT_RTC: TP23.1, U3.48 (P0_28/AIN4); also elsewhere on the board
/LED: R16.2, U3.32 (P0_08)
/PREVGH: C19.1, D3.1 (K), J3.21, TP9.1
/PREVGL: C13.1, D1.2 (A), J3.23, TP11.1
/RESE: J3.3, Q1.3 (S), R6.1, TP3.1
/SCLK: J3.13, TP18.1, U3.39 (P0_27)
/SCL_RTC: TP21.1, TP29.1, U3.11 (P0_18/TRACE_D0); also elsewhere on the board
/SDA_RTC: TP22.1, TP30.1, U3.5 (P0_14/TRACE_D3); also elsewhere on the board
/SDI: J3.14, TP19.1, U3.41 (P0_25)
/SWDCLK: J1.2, SWDCLK1.1, U3.30 (SWDCLK)
/SWDIO: J1.3, SWDIO1.1, U3.28 (SWDIO)
/SWNO: R8.2, SW2.2, U3.6 (P0_26)
/SWNW: R3.2, SW1.1, U3.3 (P0_12)
/SWSO: R10.2, SW4.1, U3.45 (P0_19)
/SWSW: R9.2, SW3.2, U3.46 (P0_29/AIN5)
/TSCL: J3.6
/TSDA: J3.7
/VCOM: C18.1, J3.24, TP12.1
/VDD: C11.1, J3.18, TP6.1
/VGH: C15.1, J3.5, TP5.1
/VGL: C10.1, J3.4, TP4.1
/VPP: C16.1, J3.19, TP7.1
/VSH: C12.1, J3.20, TP8.1
/VSL: C17.1, J3.22, TP10.1
/~CS: J3.12, TP17.1, U3.37 (P0_15/TRACE_D2)
/~RES: J3.10, TP15.1, U3.33 (P0_07)
unnamed: C14.1, D1.1 (K), D2.2 (A)
unnamed: C14.2, D3.2 (A), L2.2, Q1.2 (D)
unnamed 43: J2.2; also elsewhere on the board
unnamed 44: J2.3; also elsewhere on the board
unnamed: J4.5, J4.6, R17.1
unnamed: L1.2, U2.B1 (SW)
unnamed: Q1.1 (G), R7.1
unnamed: Q3.1 (G), R16.1
unnamed: Q3.2 (D), R17.2
unnamed: R4.1, R5.2, U2.C2 (FB)
unnamed: R13.2, R15.1, U3.38 (P0_03/AIN1)
unnamed: TP31.1, U3.2 (P0_09/NFC1)
unnamed: TP32.1, U3.4 (P0_10/NFC2)
unnamed: U3.20 (OUT_ANT), U3.22 (OUT_MOD)

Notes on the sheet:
|close to radio!|
oder 0R47
Clip
Brace
+BATT and +VDC are connected via Clip and Brace or +VDC comes from programmer.
Connect FB to GND on fixed voltage type

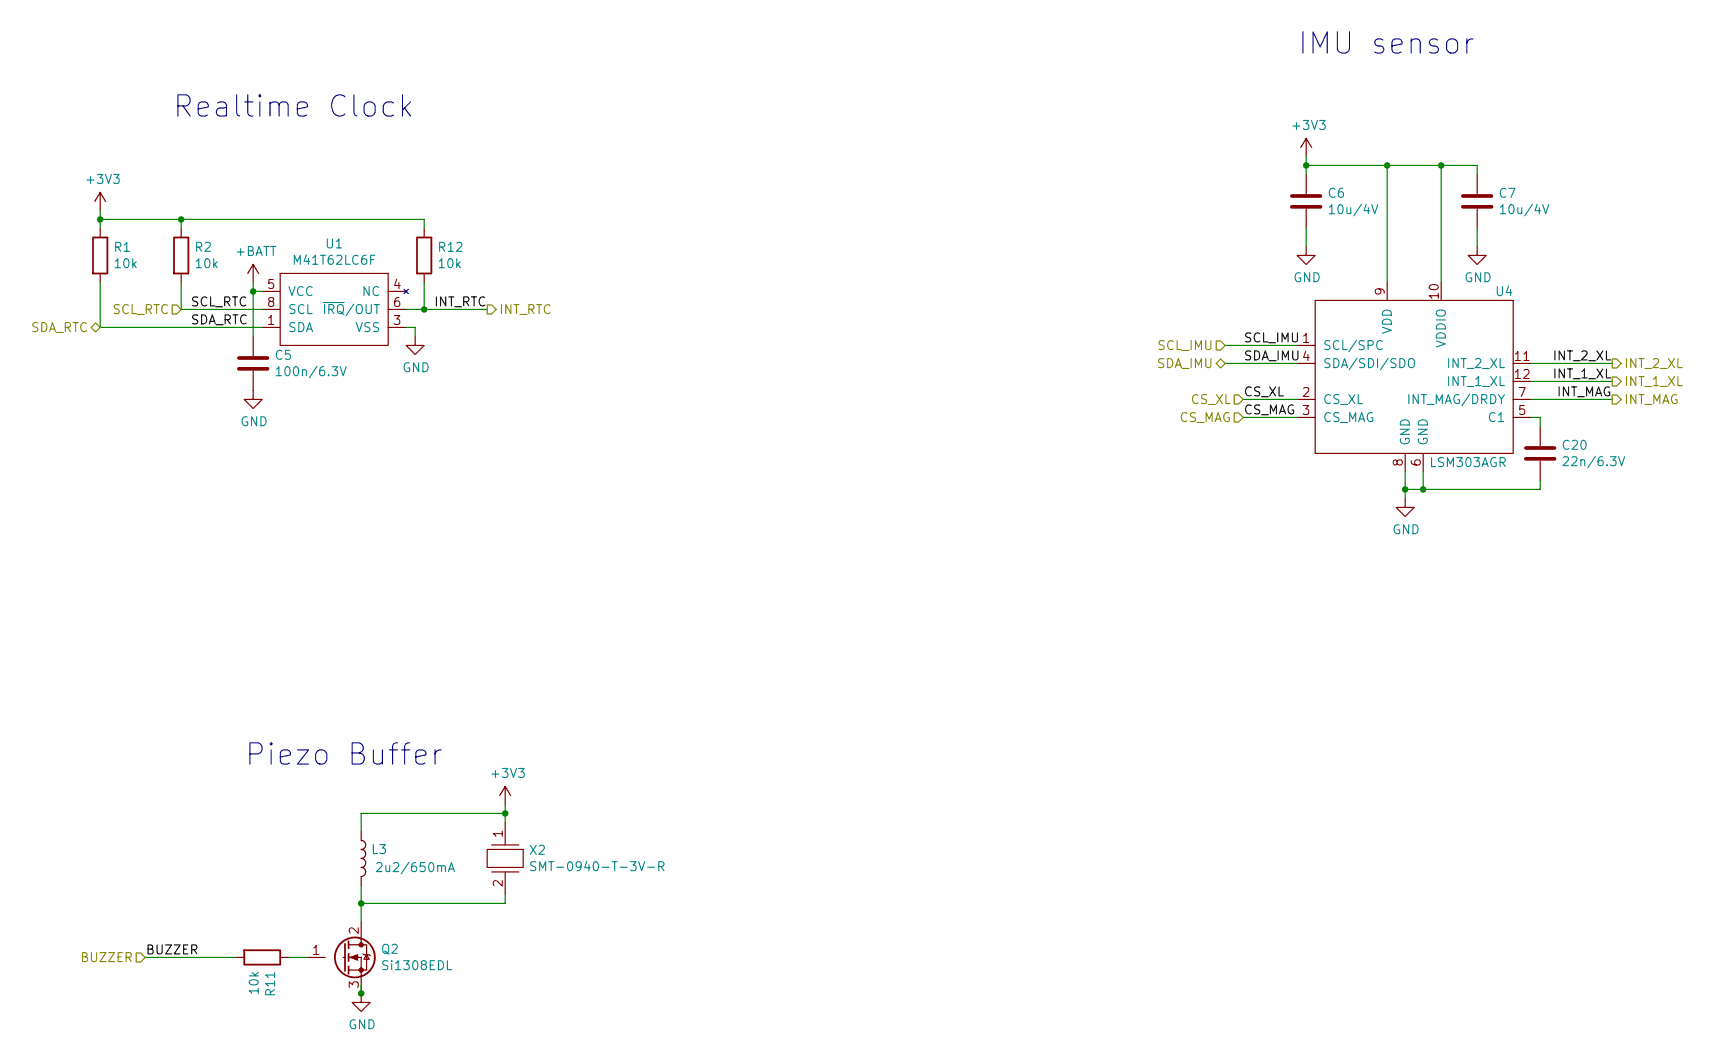
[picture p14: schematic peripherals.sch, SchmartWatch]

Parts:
C5: 100n/6.3V; C_0603_1608Metric; MPN1 GCM188R71C104KA37D
C6, C7: 10u/4V; C_0603_1608Metric; MPN1 CL10A106MQ8NNNC
C20: 22n/6.3V; C_0603_1608Metric; MPN1 GRM188R71H223KA01D
L3: 2u2/650mA; L_0805_2012Metric; MPN1 MBKK2012T2R2M
Q2: Si1308EDL; SOT-323_SC-70; MPN1 SI1308EDL-T1-GE3
R1, R2, R11, R12: 10k; R_0603_1608Metric; MPN1 RMCF0603JG10K0
U1: M41T62LC6F; LCC-8_1.5x3.2mm_P0.9mm; MPN1 M41T62LC6F
U4: LSM303AGR; LGA-12_2x2mm_P0.5mm; MPN1 LSM303AGR
X2: SMT-0940-T-3V-R; SMT-0940-T_3V-R; MPN1 SMT-0940-T-3V-R

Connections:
+3V3: C6.1, C7.1, L3.1, R1.1, R2.1, R12.1, U4.9 (VDD), U4.10 (VDDIO), X2.1; also elsewhere on the board
+BATT: C5.1, U1.5 (VCC); also elsewhere on the board
-BATT: C5.2, C6.2, C7.2, C20.2, Q2.3 (S), U1.3 (VSS), U4.6 (GND), U4.8 (GND); also elsewhere on the board
/BUZZER: R11.2; also elsewhere on the board
/CS_MAG: U4.3 (CS_MAG); also elsewhere on the board
/CS_XL: U4.2 (CS_XL); also elsewhere on the board
/INT_1_XL: U4.12 (INT_1_XL); also elsewhere on the board
/INT_2_XL: U4.11 (INT_2_XL); also elsewhere on the board
/INT_MAG: U4.7 (INT_MAG/DRDY); also elsewhere on the board
/INT_RTC: R12.2, U1.6 (~IRQ~/OUT); also elsewhere on the board
/SCL_RTC: R2.2, U1.8 (SCL), U4.1 (SCL/SPC); also elsewhere on the board
/SDA_RTC: R1.2, U1.1 (SDA), U4.4 (SDA/SDI/SDO); also elsewhere on the board
unnamed: C20.1, U4.5 (C1)
unnamed: L3.2, Q2.2 (D), X2.2
unnamed: Q2.1 (G), R11.1

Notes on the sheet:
Realtime Clock
IMU sensor
Piezo Buffer

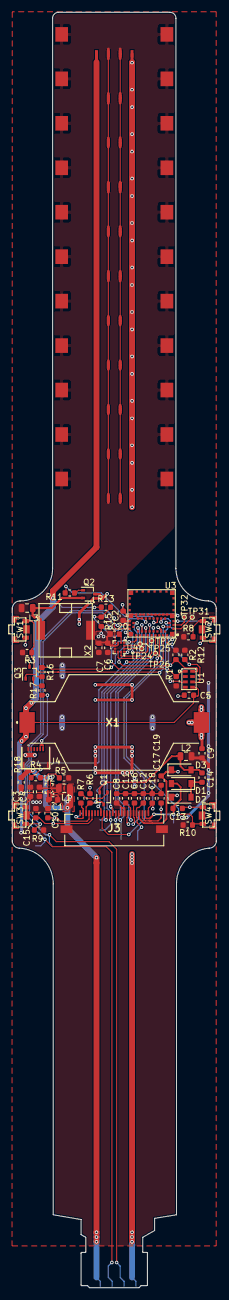
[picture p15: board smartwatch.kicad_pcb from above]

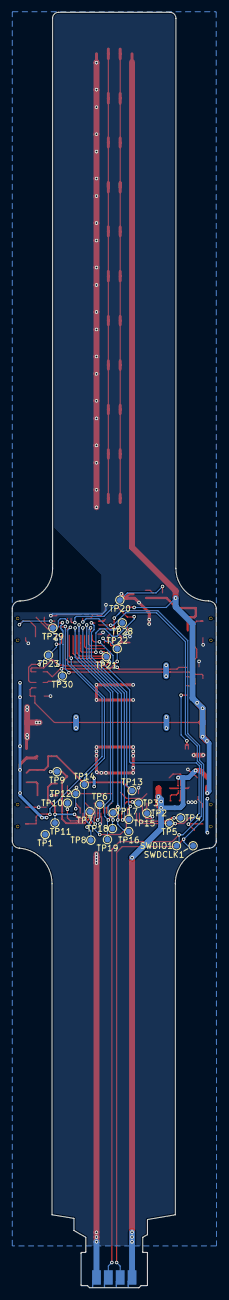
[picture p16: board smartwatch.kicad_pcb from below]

Board: 2 copper layers, 34.4 x 215.2 mm, 104 parts (29 on the bottom side), 55 nets.

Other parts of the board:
J2#2, J2#3, J2#4, J2#5, J2#6, J2#7, J2#8, J2#9, J2#10, J2#11: 505147-0490; 505147-0490_NO_SOLDER

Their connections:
+3V3: J2#2.~, J2#3.~, J2#4.~, J2#5.~, J2#6.~, J2#7.~, J2#8.~, J2#9.~, J2#10.~, J2#11.~; also elsewhere on the board
+BATT: J2#2.4, J2#3.4, J2#4.4, J2#5.4, J2#6.4, J2#7.4, J2#8.4, J2#9.4, J2#10.4, J2#11.4; also elsewhere on the board
-BATT: J2#2.1, J2#3.1, J2#4.1, J2#5.1, J2#6.1, J2#7.1, J2#8.1, J2#9.1, J2#10.1, J2#11.1; also elsewhere on the board
unnamed 43: J2#2.2, J2#3.2, J2#4.2, J2#5.2, J2#6.2, J2#7.2, J2#8.2, J2#9.2, J2#10.2, J2#11.2; also elsewhere on the board
unnamed 44: J2#2.3, J2#3.3, J2#4.3, J2#5.3, J2#6.3, J2#7.3, J2#8.3, J2#9.3, J2#10.3, J2#11.3; also elsewhere on the board

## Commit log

2019-02-20 initial commit for review
    [peripherals.sch, smartwatch.csv, smartwatch.kicad_pcb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]
2019-02-20 add schematic PDF
2019-02-20 move R18 reference so it does not overlap with C3 and C4
    [smartwatch.kicad_pcb]
2019-02-20 J3 and J4 SMD mounting pads are connected to +3V3 plane for stability. X2 is rotated to be alongside the bend radious if watch is worn. also for stability. traces leading to buzzer are thickened for 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
    [smartwatch.kicad_pcb]
2019-02-20 connect solder tabs of clasp connector J2 to plane for stability. pads are connected with thermal relief for easy soldering
    [smartwatch.kicad_pcb]
2019-02-20 Fix: put L1 closer to SW pin of TPS610994; add more vias to power traces
    [smartwatch.kicad_pcb]
2019-02-20 Fix: move via to close 3V3 plane next to batt+ voltage line.
    [smartwatch.kicad_pcb]
2019-02-20 Fix: increase -BATT thickness for capacitor bank of display.
    [smartwatch.kicad_pcb]
2019-02-21 FIX: increase thickness of traces on wristband clasp so the pads extend under the solder resist.
    [smartwatch.kicad_pcb]
2019-02-21 Add render of PCB
